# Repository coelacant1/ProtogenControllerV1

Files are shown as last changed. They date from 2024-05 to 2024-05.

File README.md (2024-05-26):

# ProtogenControllerV1
Protogen Controller V1 with Bluetooth

## General Information
This controller is used to control up to 8 WS2812 strips at 500 pixels long each. This supports an ESP32 WROVER used for communication to other wireless devices that talks to the Teensy 4.0 over Serial. Both devices have breakouts for I2C and SPI as well as all unused GPIO. The ESP32 is programmed over USB using the integrated CP2104 FTDI.

## Bill of Materials

| **RefDes** | **Value** | **Footprint** | **Quantity** | **Description** |
|---|---|---|---|---|
| C1, C2, C3, C4, C5, C6, C7, C8, DC1, DC2, DC3, DC4, DC5, DC6, DC7, DC8 | CC0805KKX7R6BB105 | 0805 | 16 | CAP CER 1UF 10V X7R |
| J1 | 47589-0001 | | 1 | Right Angle Female Type AB Micro USB Connector, 30 V, 1.8 A, -30 to 85 degC, RoHS, Tape and Reel |
| J1_JSTBreakout1, J1_JSTBreakout2, J1_JSTBreakout3, J1_JSTBreakout4, J1_JSTBreakout5, J1_JSTBreakout6, J1_JSTBreakout7, J1_JSTBreakout8 | B3B-XH-A(LF)(SN) | 2.5MM | 8 | CONN HEADER VERT 3POS |
| J2 | XT30-F | | 1 | XT30 Female connector for board mount |
| LED1, LED2, LED3 | 150080SS75000 | | 3 | SMD mono-color Chip LED, WL-SMCW, Super Red |
| P1 | Header 16X2 | | 1 | Header, 16-Pin, Dual row |
| P2, P3 | Header 4X2 | | 2 | Header, 4-Pin, Dual row |
| P4, P5 | Header 6X2 | | 2 | Header, 6-Pin, Dual row |
| P6 | Header 2 | | 1 | Header, 2-Pin |
| Q1, Q2 | MMBT2222ALT1G | SOT-23 | 2 | General Purpose Transistor, NPN Silicon, 3-Pin, Pb-Free, Tape and Reel |
| Q3 | FDN339AN | SSOT3 | 1 | MOSFET N-CH 20V 3A |
| Q4 | FDN340P | SSOT3 | 1 | MOSFET P-CH 20V 2A |
| R1, R2, R3, R4, R5, R6, R9, R10, R14, R15, R16, R17, R18, R19, R20 | CRCW08050000Z0EA  | | 15 | |
| R7, R8, R13 | CAT16-103J4LF | 8-Pin SMD | 3 | CAT / CAY 16 Series - Chip Resistor Array, 10 KOhm, +/- 5%, 50 V, -55 to 125 degC, RoHS, Tape and Reel |
| SW1 | FSMSMTR | 2-Pin SMD | 1 | FSMSM Push Button Switch, 50 mA, -35 to 85 degC, RoHS, Tape and Reel |
| U1 | ESP32-WROVER-B_(16MB)| | 1 | Generic WiFi-BT-BLE MCU module. Flash memory of 16 MB and PSRAM of 8 MB |
| U2 | Teensy 4.0 | | 1 | RT1062 Teensy 4.0 i.MX ARM® Cortex®-M7 MPU Embedded Evaluation Board |
| U4 | AP2112K-3.3TRG1 | SOT25 | 1 | IC REG LINEAR 3.3V 600MA |
| U5 | CP2104-F03-GM | 24-pin QFN | 1 | Single-Chip USB to UART Bridge, 4 Dig I/O Pins, Internal Oscillator, 1024 Bytes EEPROM, -40 to 85 degC|
| U6 | SN74HCT245DWR | 20SOIC | 1 | IC TXRX NON-INVERT 5.5V |

## Power Setup

### Powering the Teensy 4.0 for Programming
For programming the Teensy 4.0, the bottom VIN from VUSB trace needs to be cut to not provide power to the LED boards and cause damage while programming.

### Powering the Controller for Usage
To use the controller, 5V must be provided to the XT30 connector. Make sure you follow the standards for the XT30 polarity!

## Sensors/Peripherals

### Boop Sensor (APDS-9960)
The APDS-9960 is a Time-of-Flight sensor that uses an IR light to measure the distance to the object in front of it using the I2C communication protocol. This can be connected on either the Teensy I2C breakout or the ESP32 I2C breakout. The following picture shows the recommended location for the device:

### MAX9814 Microphone
The MAX9814 electret microphone is a standard electret microphone with automatic gain compensation via an amplifier. This will pick up a varying range of sounds and not just your voice, so it is best to tune the software gain appropriately.

### Control Button
The control button is a simple button that allows you to toggle between faces. There is no analog filtering on the button with the kit as the button debouncing is handled in code within the ButtonHandler class.

### I2C OLED Display
The OLED display is a small display for mounting within the visor for the wearer to see. It is used to display the current face being displayed on the outside, status of a battery, or anything else you like. This will communicate over I2C with either the Teensy or the ESP32.

## Programming the Teensy

### Getting Started with ProtoTracer

#### Install Applications
- Install Visual Studio Code from here: [Visual Studio Code](https://code.visualstudio.com/)
- Install TeensyDuino from here: [TeensyDuino](https://www.pjrc.com/teensy/td_download.html)

#### Install Extensions
- Install PlatformIO IDE under the extensions in Visual Studio Code.
- Install C/C++ extension.

#### Download the Codebase
Download ProtoTracer from here: [ProtoTracer](https://github.com/coelacant1/ProtoTracer). You can use either the Zip download or clone it to a local Git repository.

## General Recommendations and Notes
- Do not use external power to the XT30 connector, unless it is 5V directly, the controller should be able to handle 4.5V to 5.5V but anything else is outside of specification.
- Do not short circuit the IO pins. Be careful about which pins are in use and are listed at the beginning of the guide.
- Be careful leaving the electronics in a humid environment.

## Images

### 3D View
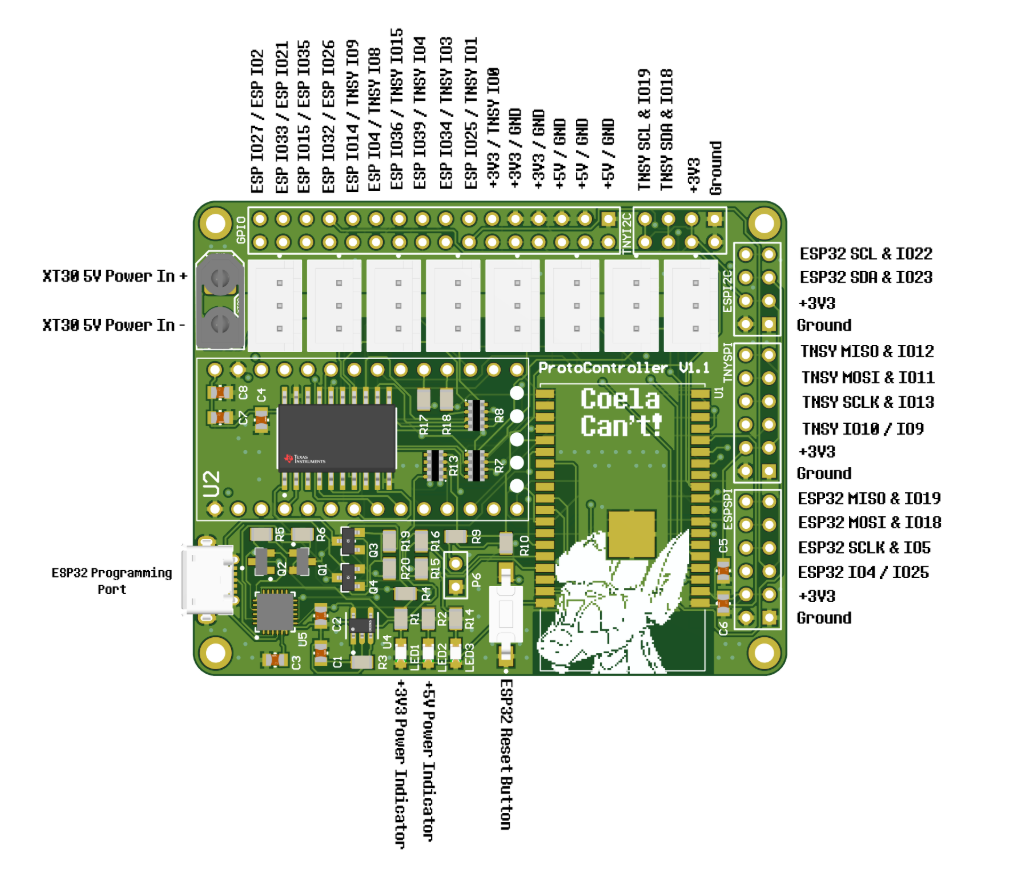
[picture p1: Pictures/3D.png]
3D View


### Wiring
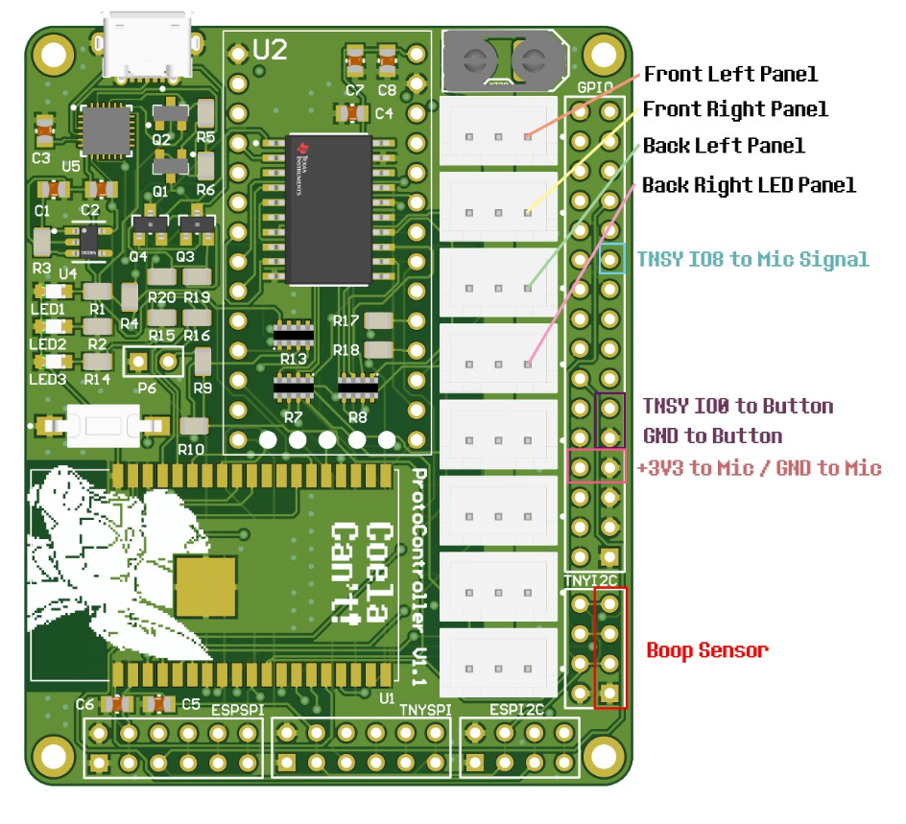
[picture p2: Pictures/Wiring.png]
Wiring


### Layer View
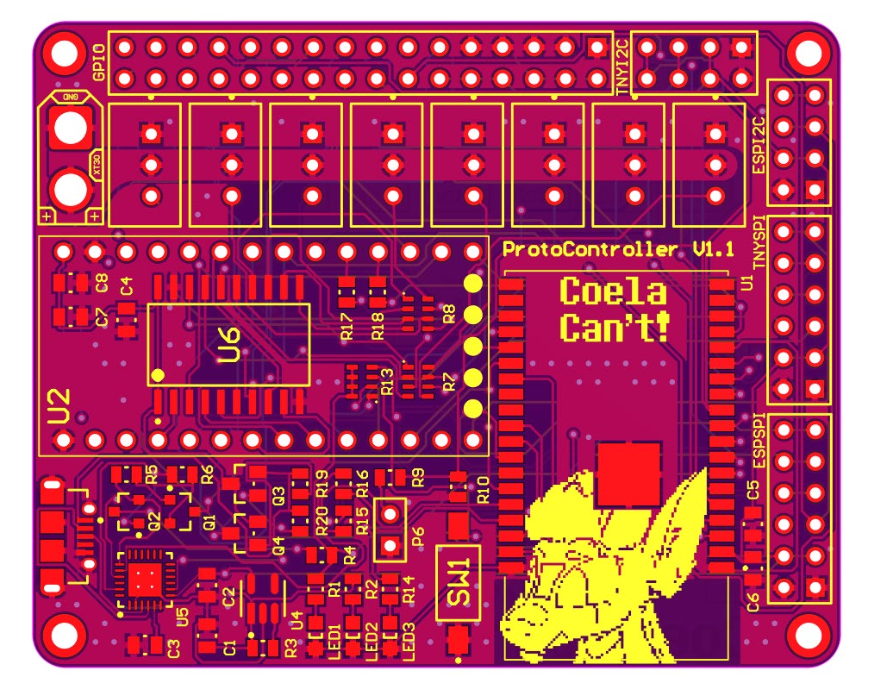
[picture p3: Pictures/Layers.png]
Layer View


### Electrical Schematic
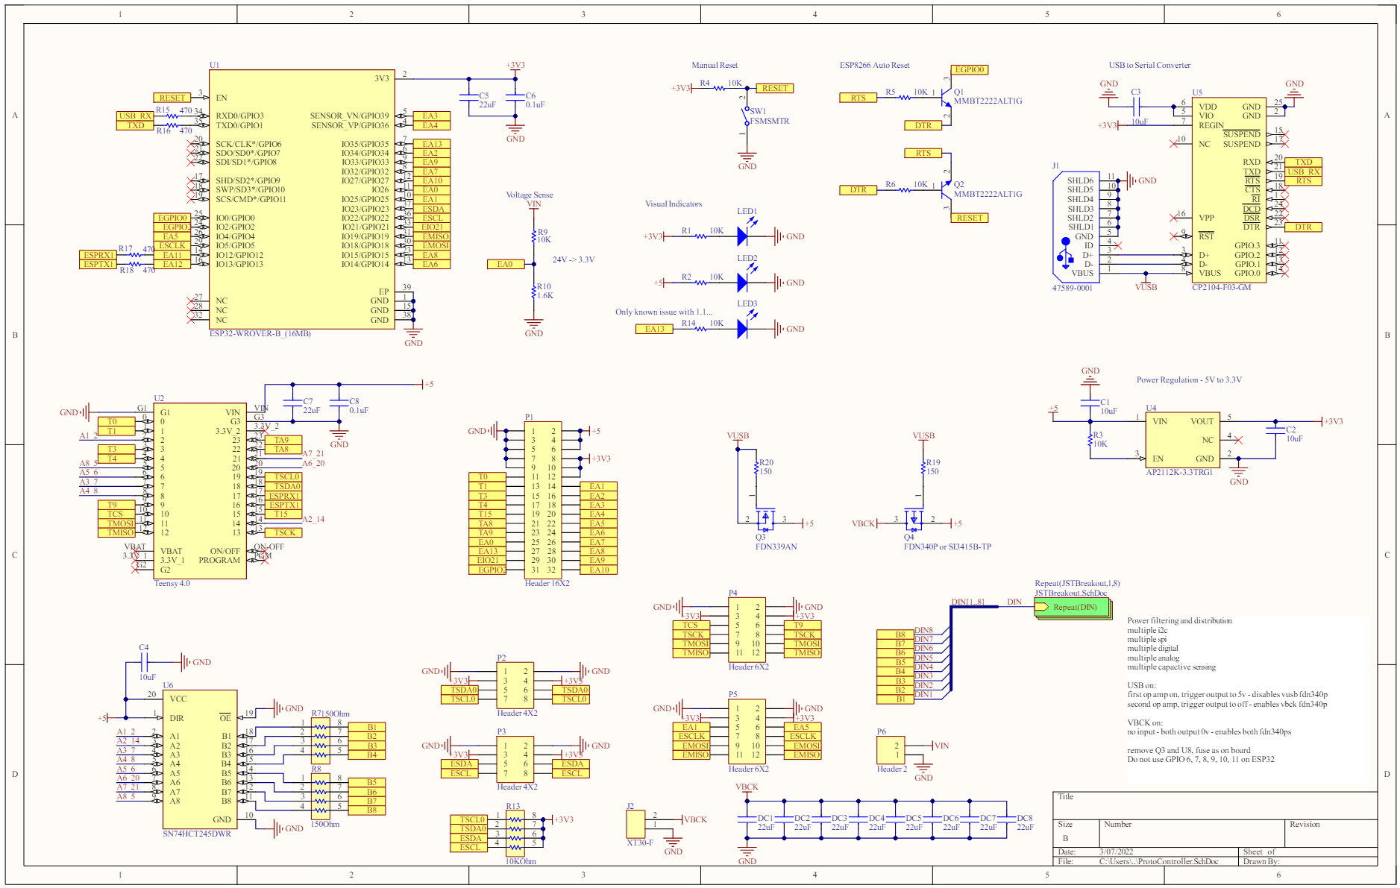
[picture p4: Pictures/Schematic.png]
Electrical Schematic


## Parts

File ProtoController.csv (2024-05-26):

Line # | Name | Description | Designator | Revision ID | Revision State | Revision Status | Quantity | Manufacturer 1 | Manufacturer Part Number 1 | Manufacturer Lifecycle 1 | Supplier 1 | Supplier Part Number 1 | Supplier Unit Price 1 | Supplier Subtotal 1
 | CC0805KKX7R6BB105 | CAP CER 1UF 10V X7R 0805 | C1, C2, C3, C4, C5, C6, C7, C8, DC1, DC2, DC3, DC4, DC5, DC6, DC7, DC8 | CMP-03422-000182-1 | New From Design | Up to date | 16 | Yageo | CC0805KKX7R6BB105 | Volume Production | Newark | 68R4879 | 0.029 | 0.464
 | 47589-0001 | Right Angle Female Type AB Micro USB Connector, 30 V, 1.8 A, -30 to 85 degC, RoHS, Tape and Reel | J1 | CMP-2000-05610-1 | Released | Up to date | 1 | Molex | 47589-0001 | Volume Production | Newark | 40P3749 | 0.536 | 0.536
 | B3B-XH-A(LF)(SN) | CONN HEADER VERT 3POS 2.5MM | J1_JSTBreakout1, J1_JSTBreakout2, J1_JSTBreakout3, J1_JSTBreakout4, J1_JSTBreakout5, J1_JSTBreakout6, J1_JSTBreakout7, J1_JSTBreakout8 | CMP-17439-000014-2 | New From Design | Out of date | 8 | JST | B3B-XH-A(LF)(SN) | Unknown | Newark | 73M9431 | 0.061 | 0.488
 | XT30-F | XT30 Female connector for board mount | J2 | CMP-002-00076-4 | Draft | Up to date | 1
 | 150080SS75000 | SMD mono-color Chip LED, WL-SMCW, Super Red | LED1, LED2, LED3 | CMP-1426-00010-1 | Released | Out of date | 3 | Wurth Electronics | 150080SS75000 | Volume Production | Mouser | 710-150080SS75000 | 0.19 | 0.57
 | Header 16X2 | Header, 16-Pin, Dual row | P1 |  | Not managed |  | 1
 | Header 4X2 | Header, 4-Pin, Dual row | P2, P3 |  | Not managed |  | 2
 | Header 6X2 | Header, 6-Pin, Dual row | P4, P5 |  | Not managed |  | 2
 | Header 2 | Header, 2-Pin | P6 |  | Not managed |  | 1
 | MMBT2222ALT1G | General Purpose Transistor, NPN Silicon, 3-Pin SOT-23, Pb-Free, Tape and Reel | Q1, Q2 | CMP-1048-00538-1 | Released | Up to date | 2 | ON Semiconductor | MMBT2222ALT1G | Volume Production | Newark | 84K8795 | 0.019 | 0.038
 | FDN339AN | MOSFET N-CH 20V 3A SSOT3 | Q3 | CMP-2000-06252-2 | New From Design | Up to date | 1 | ON Semiconductor / Fairchild | FDN339AN | Volume Production | Newark | 34C0138 | 0.196 | 0.196
 | FDN340P | MOSFET P-CH 20V 2A SSOT3 | Q4 | CMP-2100-03638-2 | New From Design | Up to date | 1 | ON Semiconductor / Fairchild | FDN340P | Volume Production | Newark | 58K8841 | 0.142 | 0.142
 | CRCW08050000Z0EA |  | R1, R2, R3, R4, R5, R6, R9, R10, R14, R15, R16, R17, R18, R19, R20 | CMP-2001-04896-1 | Released | Up to date | 15 | Vishay | CRCW08050000Z0EA | Volume Production | Newark | 52K9721 | 0.006 | 0.09
 | CAT16-103J4LF | CAT / CAY 16 Series - Chip Resistor Array, 10 KOhm, +/- 5%, 50 V, -55 to 125 degC, 8-Pin SMD, RoHS, Tape and Reel | R7, R8, R13 | CMP-2000-06067-1 | Released | Up to date | 3 | Bourns | CAT16-103J4LF | Volume Production | Digikey | CAT16-103J4LFCT-ND | 0.1 | 0.3
 | FSMSMTR | FSMSM Push Button Switch, 50 mA, -35 to 85 degC, 2-Pin SMD, RoHS, Tape and Reel | SW1 | CMP-2000-07501-1 | Released | Up to date | 1 | TE Connectivity | FSMSMTR | Unknown
 | ESP32-WROVER-B_(16MB) | Generic WiFi-BT-BLE MCU module. Flash memory of 16 MB and PSRAM of 8 MB | U1 | CMP-056-0000-3 | Draft | Up to date | 1
 | Teensy 4.0 | RT1062 Teensy 4.0 i.MX ARM® Cortex®-M7 MPU Embedded Evaluation Board | U2 | CMP-023-0000-2 | Draft | Out of date | 1
 | AP2112K-3.3TRG1 | IC REG LINEAR 3.3V 600MA SOT25 | U4 | CMP-12756-000035-1 | New From Design | Up to date | 1 | Diodes | AP2112K-3.3TRG1 | Volume Production | Mouser | 621-AP2112K-3.3TRG1 | 0.22 | 0.22
 | CP2104-F03-GM | Single-Chip USB to UART Bridge, 4 Dig I/O Pins, Internal Oscillator, 1024 Bytes EEPROM, -40 to 85 degC, 24-pin QFN | U5 | CMP-0511-00004-1 | Released | Out of date | 1 | Silicon Labs | CP2104-F03-GM | Volume Production | Arrow Electronics | CP2104-F03-GM | 3.18 | 3.18
 | SN74HCT245DWR | IC TXRX NON-INVERT 5.5V 20SOIC | U6 | CMP-1620-00207-3 | New From Design | Up to date | 1 | Texas Instruments | SN74HCT245DWR | Volume Production | Arrow Electronics | SN74HCT245DWR | 0.6118 | 0.6118

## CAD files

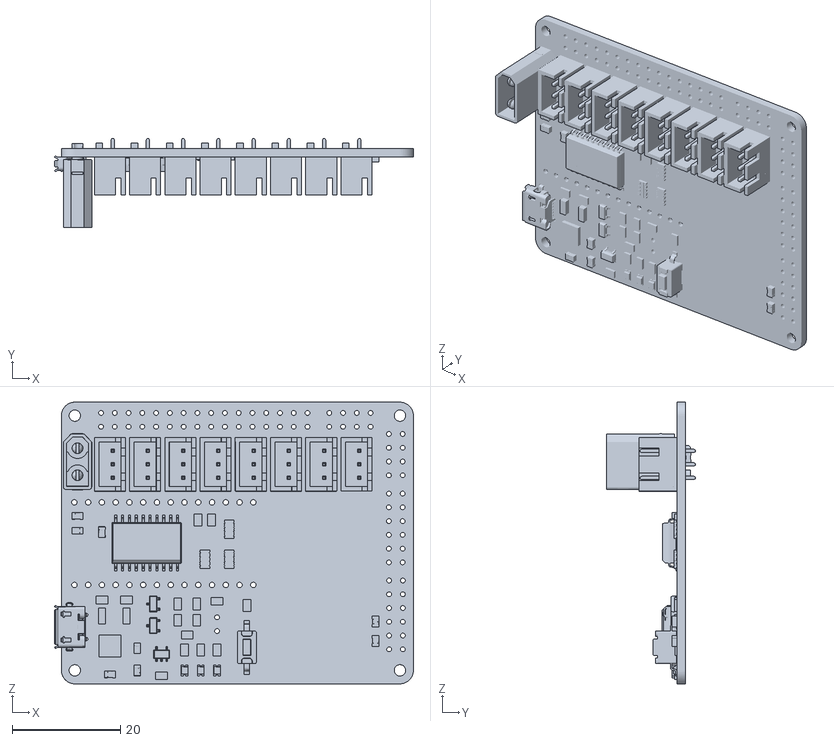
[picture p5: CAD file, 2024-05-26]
ProtoController.stl
66.3 x 16.4 x 52.0

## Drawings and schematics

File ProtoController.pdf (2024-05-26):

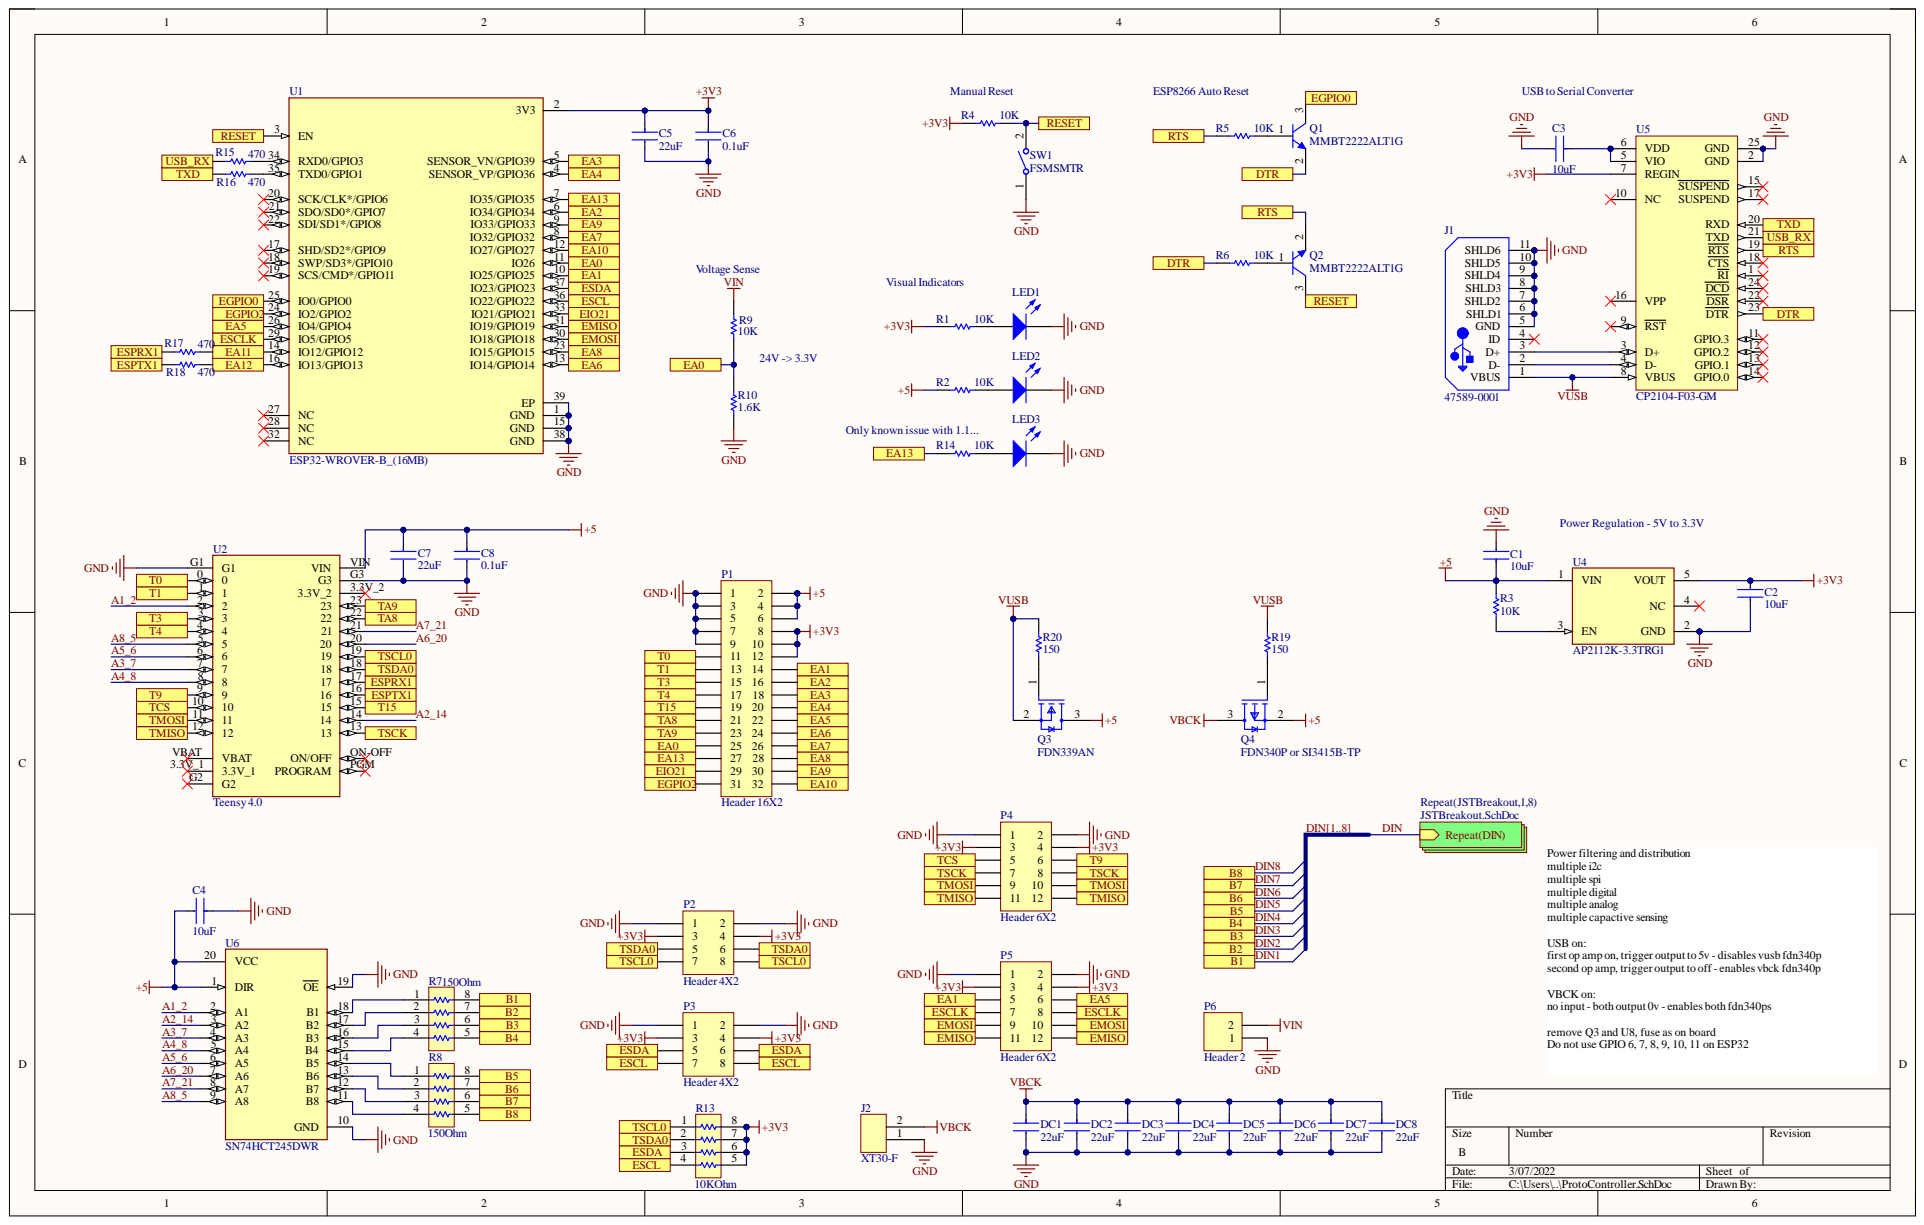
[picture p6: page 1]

Only known issue with 1.1...

USB on:
first op amp on, trigger output to 5v - disables vusb fdn340p
second op amp, trigger output to off - enables vbck fdn340p

VBCK on:
no input- both output 0v - enables both fdn340ps

remove Q3 and U8, fuse as on board
Do not use GPIO 6, 7, 8, 9, 10, 11 on ESP32

TSDA0 | 3 | 6
ESDA | 4 | 5

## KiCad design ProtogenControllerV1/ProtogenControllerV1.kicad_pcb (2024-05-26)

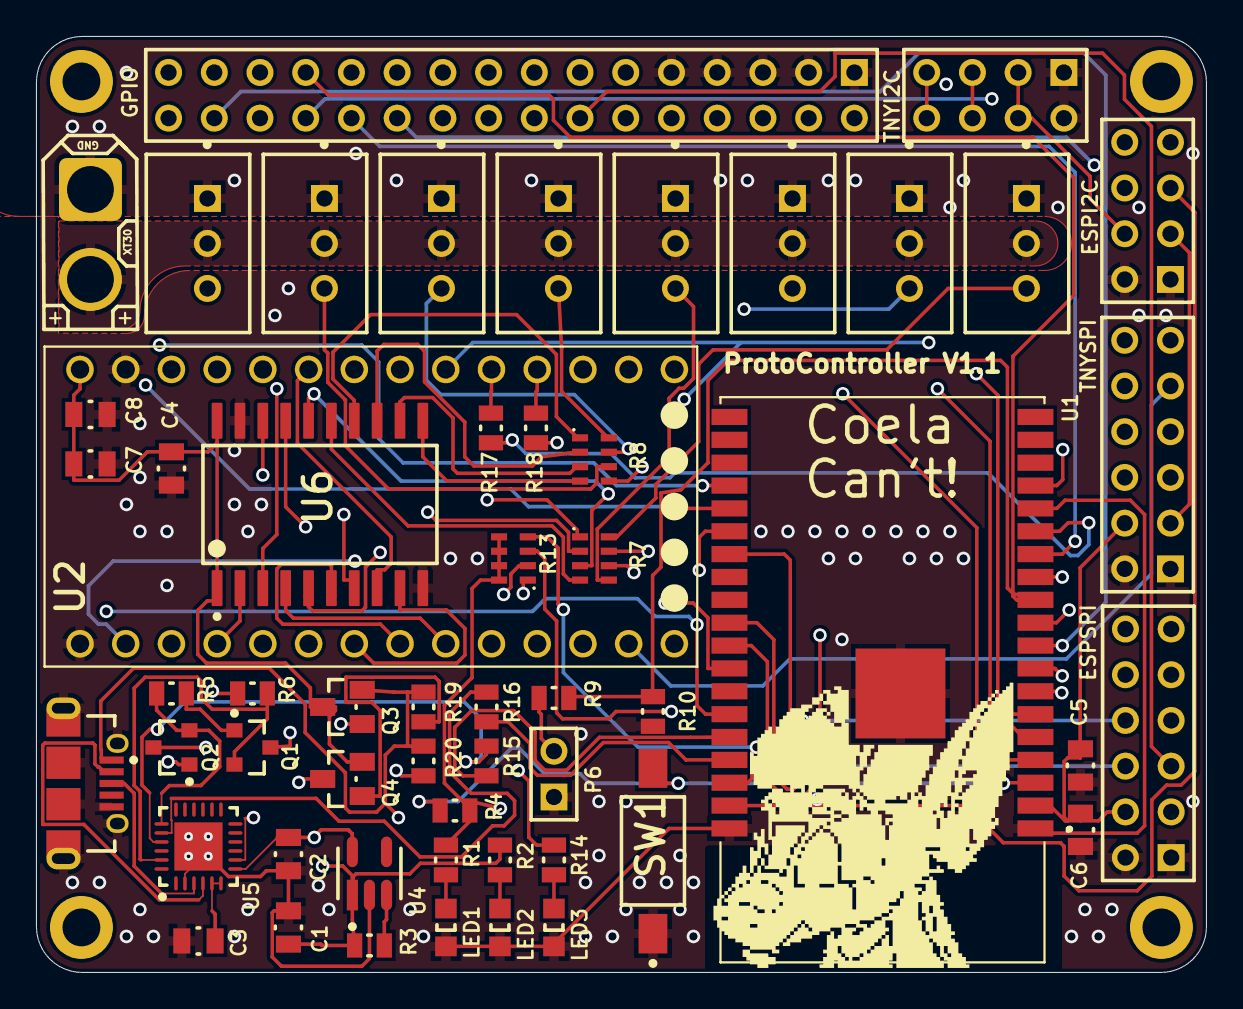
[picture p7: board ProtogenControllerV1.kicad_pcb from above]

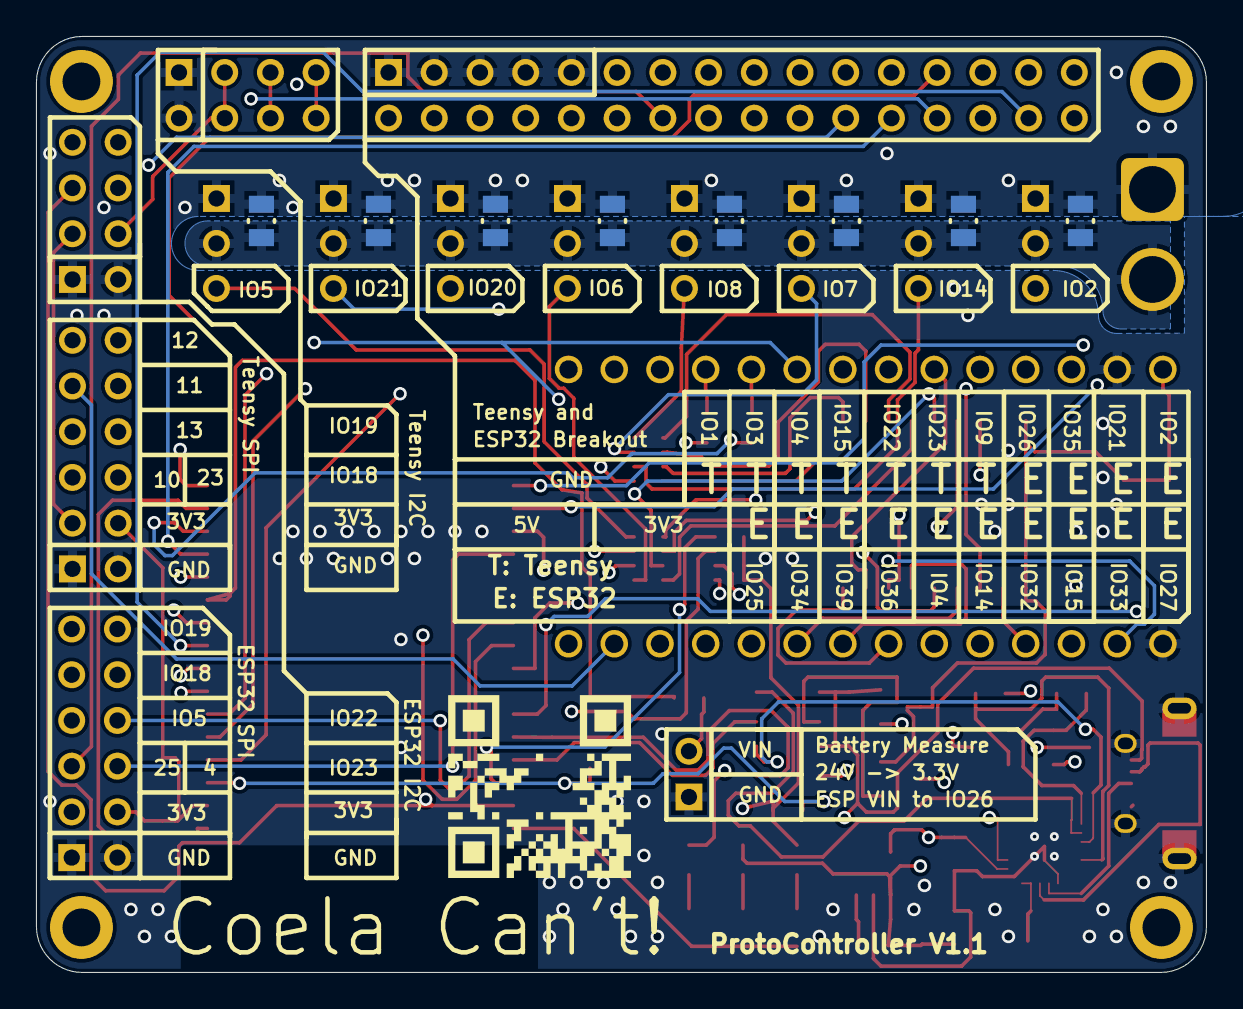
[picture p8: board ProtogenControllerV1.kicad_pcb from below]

Board: 4 copper layers, 65.0 x 52.0 mm, 62 parts (8 on the bottom side), 84 nets.

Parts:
C1, C2, C3, C4, C5, C6, C7, C8: CC0805KKX7R6BB105; FP-CC0805-0_85-MFG
DC1, DC2, DC3, DC4, DC5, DC6, DC7, DC8: CC0805KKX7R6BB105; FP-CC0805-0_85-MFG
ESPSPI: Header 6X2; HDR2X6
GPIO: Header 16X2; HDR2X16
J1_JSTBreakout1, J1_JSTBreakout2, J1_JSTBreakout3, J1_JSTBreakout4, J1_JSTBreakout5, J1_JSTBreakout6, J1_JSTBreakout7, J1_JSTBreakout8: B3B-XH-A(LF)(SN); FP-B3B-XH-A_LF_SN-MFG
J2: XT30-F; XT30-F-Footprint-1
LED1, LED2, LED3: 150080SS75000; 0805_A
P2, P3: Header 4X2; HDR2X4
P6: Header 2; HDR1X2
Q1, Q2: MMBT2222ALT1G; ONSC-SOT-23-3-318-08_V
Q3: FDN339AN; FP-527AG-MFG
Q4: FDN340P; FP-527AG-MFG
R1, R2, R3, R4, R5, R6, R9, R10, R14, R15, R16, R17, R18, R19, R20: CRCW08050000Z0EA; RESC2013X50X30LL20T20
R7, R8, R13: CAT16-103J4LF; BOUR-CAT16-103J4LF_L
SW1: FSMSMTR; TECO-FSMSMTR_V
TNYSPI: Header 6X2; HDR2X6
U1: ESP32-WROVER-B_(16MB); XCVR_ESP32-WROVER-B_(16MB)
U2: Teensy 4.0; MODULE_DEV-15583
U4: AP2112K-3.3TRG1; FP-SOT25-IPC_A
U5: CP2104-F03-GM; SLAB-QFN-24-2675x2675TP_M
U6: SN74HCT245DWR; FP-DW0020A-MFG

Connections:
+3V3: C2.2, C5.1, C6.1, ESPSPI.3, ESPSPI.4, GPIO.8, GPIO.10, GPIO.12, P2.3, P2.4, P3.3, P3.4, R1.1, R4.1, R13.5, R13.6, R13.7, R13.8, TNYSPI.3, TNYSPI.4, U1.2, U4.5, U5.7
+5: C1.1, C4.2, C7.1, C8.1, GPIO.2, GPIO.4, GPIO.6, Q3.3, Q4.2, R2.1, R3.2, U2.VIN, U4.1, U6.1, U6.20
A1_2: U2.2, U6.2
A2_14: U2.14, U6.3
A3_7: U2.7, U6.4
A4_8: U2.8, U6.5
A5_6: U2.6, U6.6
A6_20: U2.20, U6.7
A7_21: U2.21, U6.8
A8_5: U2.5, U6.9
DIN1: J1_JSTBreakout1.3, R7.8
DIN2: J1_JSTBreakout2.3, R7.7
DIN3: J1_JSTBreakout3.3, R7.6
DIN4: J1_JSTBreakout4.3, R7.5
DIN5: J1_JSTBreakout5.3, R8.8
DIN6: J1_JSTBreakout6.3, R8.7
DIN7: J1_JSTBreakout7.3, R8.6
DIN8: J1_JSTBreakout8.3, R8.5
GND: C1.2, C2.1, C3.2, C4.1, C5.2, C6.2, C7.2, C8.2, DC1.2, DC2.2, DC3.2, DC4.2, DC5.2, DC6.2, DC7.2, DC8.2, ESPSPI.1, ESPSPI.2, GPIO.1, GPIO.3, GPIO.5, GPIO.7, GPIO.9, J1_JSTBreakout1.1, J1_JSTBreakout2.1, J1_JSTBreakout3.1, J1_JSTBreakout4.1, J1_JSTBreakout5.1, J1_JSTBreakout6.1, J1_JSTBreakout7.1, J1_JSTBreakout8.1, J2.1, LED1.1, LED2.1, LED3.1, P2.1, P2.2, P3.1, P3.2, P6.1, R10.2, SW1.1, TNYSPI.1, TNYSPI.2, U1.1, U1.15, U1.38, U1.39, U2.G1, U2.G3, U4.2, U5.2, U5.25, U6.10, U6.19
NetC3_1: C3.1, U5.5, U5.6
NetLED1_2: LED1.2, R1.2
NetLED2_2: LED2.2, R2.2
NetLED3_2: LED3.2, R14.2
NetP1_11: GPIO.11, U2.0
NetP1_13: GPIO.13, U2.1
NetP1_14: ESPSPI.5, GPIO.14, U1.10
NetP1_15: GPIO.15, U2.3
NetP1_16: GPIO.16, U1.6
NetP1_17: GPIO.17, U2.4
NetP1_18: GPIO.18, U1.5
NetP1_19: GPIO.19, U2.15
NetP1_20: GPIO.20, U1.4
NetP1_21: GPIO.21, U2.22
NetP1_22: ESPSPI.6, GPIO.22, U1.26
NetP1_23: GPIO.23, U2.23
NetP1_24: GPIO.24, U1.13
NetP1_25: GPIO.25, R9.2, R10.1, U1.11
NetP1_26: GPIO.26, U1.8
NetP1_27: GPIO.27, R14.1, U1.7
NetP1_28: GPIO.28, U1.23
NetP1_29: GPIO.29, U1.33
NetP1_30: GPIO.30, U1.9
NetP1_31: GPIO.31, U1.24
NetP1_32: GPIO.32, U1.12
NetP2_5: P2.5, P2.6, R13.2, U2.18
NetP2_7: P2.7, P2.8, R13.1, U2.19
NetP3_5: P3.5, P3.6, R13.3, U1.37
NetP3_7: P3.7, P3.8, R13.4, U1.36
NetP4_5: TNYSPI.5, U2.10
NetP4_6: TNYSPI.6, U2.9
NetP4_7: TNYSPI.7, TNYSPI.8, U2.13
NetP4_9: TNYSPI.9, TNYSPI.10, U2.11
NetP4_11: TNYSPI.11, TNYSPI.12, U2.12
NetP5_7: ESPSPI.7, ESPSPI.8, U1.29
NetP5_9: ESPSPI.9, ESPSPI.10, U1.30
NetP5_11: ESPSPI.11, ESPSPI.12, U1.31
NetQ1_1: Q1.1, R5.2
NetQ1_2: Q1.2, R6.1, U5.23
NetQ1_3: Q1.3, U1.25
NetQ2_1: Q2.1, R6.2
NetQ2_2: Q2.2, R5.1, U5.19
NetQ2_3: Q2.3, R4.2, SW1.2, U1.3
NetQ3_1: Q3.1, R20.1
NetQ4_1: Q4.1, R19.1
NetR3_1: R3.1, U4.3
NetR7_1: R7.1, U6.18
NetR7_2: R7.2, U6.17
NetR7_3: R7.3, U6.16
NetR7_4: R7.4, U6.15
NetR8_1: R8.1, U6.14
NetR8_2: R8.2, U6.13
NetR8_3: R8.3, U6.12
NetR8_4: R8.4, U6.11
NetR15_1: R15.1, U5.21
NetR15_2: R15.2, U1.34
NetR16_1: R16.1, U5.20
NetR16_2: R16.2, U1.35
NetR17_1: R17.1, U2.17
NetR17_2: R17.2, U1.14
NetR18_1: R18.1, U2.16
NetR18_2: R18.2, U1.16
VBCK: DC1.1, DC2.1, DC3.1, DC4.1, DC5.1, DC6.1, DC7.1, DC8.1, J1_JSTBreakout1.2, J1_JSTBreakout2.2, J1_JSTBreakout3.2, J1_JSTBreakout4.2, J1_JSTBreakout5.2, J1_JSTBreakout6.2, J1_JSTBreakout7.2, J1_JSTBreakout8.2, J2.2, Q4.3
VIN: P6.2, R9.1
VUSB: Q3.2, R19.2, R20.2, U5.8
